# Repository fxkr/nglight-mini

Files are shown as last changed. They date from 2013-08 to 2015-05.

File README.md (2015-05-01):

# nglight-mini r0

## What is it?

A tiny, I2C-controlled 6-channel low-side PWM LED driver based on the PCA9685.
It's just a smaller version of this: http://ng.uavp.ch/moin/Documentation/NGlight

Both schematic and layout are proven.

## Part list?

See parts.csv

## Images

r1-top
r1-bot
r1-both

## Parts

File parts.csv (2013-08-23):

Part | Quantity | Value | Type | Link
C1 | 1 | 100nF | SMD 0805 Cap
C2 | 1 | 10uF |  | https://secure.reichelt.de/?ARTICLE=31906
I2C | 1 | Molex 53261-04 | Molex Picoblade Conn Header 4Pos 1.25MM | http://www.digikey.de/product-detail/de/0532610471/WM7622CT-ND/699109?cur=USD
Q1, Q2, Q3 | 3 | Rohm QS6K1 | Dual N-Ch MOSFET | http://www.digikey.com/product-detail/en/QS6K1TR/QS6K1CT-ND/721551?cur=USD
RN1, RN2 | 2 | 240R | Resistor Array | http://www.digikey.com/product-detail/en/TC164-JR-07220RL/TC164J-220CT-ND/1005375?cur=USD
RN3, RN4 | 2 | 18K | Resistor Array

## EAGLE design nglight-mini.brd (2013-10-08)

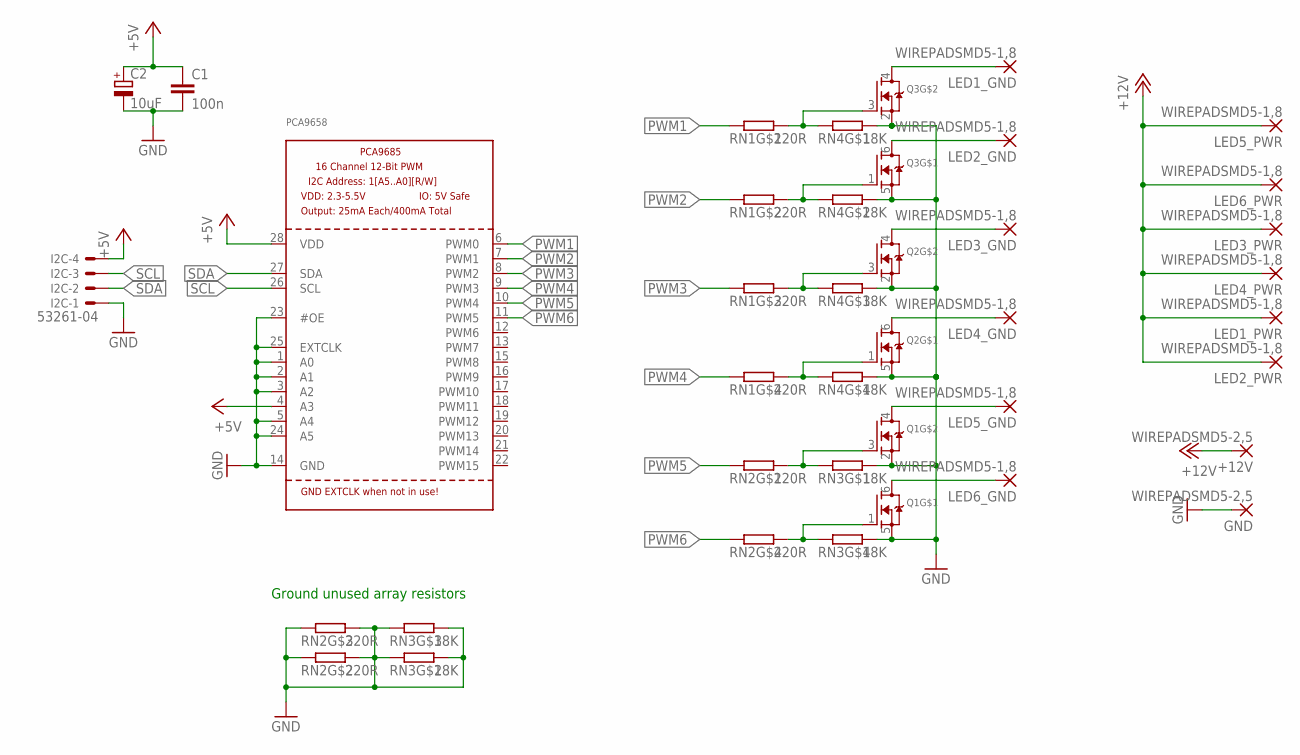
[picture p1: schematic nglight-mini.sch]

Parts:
+12V: WIREPADSMD5-2,5; 5-2,5
C1: 100n; C0805
C2: 10uF; UD-5X5,8_NICHICON
GND: WIREPADSMD5-2,5; 5-2,5
I2C: 53261-04
LED1_GND, LED1_PWR, LED2_GND, LED2_PWR, LED3_GND, LED3_PWR, LED4_GND, LED4_PWR, LED5_GND, LED5_PWR, LED6_GND, LED6_PWR: WIREPADSMD5-1,8; 5-1,8
PCA9658: PCA9685; TSSOP28
Q1, Q2, Q3: MOSFET-N; SOT23-6
RN1, RN2: 220R; 0603_ARRAY_4
RN3, RN4: 18K; 0603_ARRAY_4

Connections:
+5V: C1.1, C2.+, I2C.4, PCA9658.4 (A3), PCA9658.28 (VDD)
+12V: +12V.1, LED1_PWR.1, LED2_PWR.1, LED3_PWR.1, LED4_PWR.1, LED5_PWR.1, LED6_PWR.1
GND: C1.2, C2.-, GND.1, I2C.1, PCA9658.1 (A0), PCA9658.2 (A1), PCA9658.3 (A2), PCA9658.5 (A4), PCA9658.14 (GND), PCA9658.23 (#OE), PCA9658.24 (A5), PCA9658.25 (EXTCLK), Q1.2 (S), Q1.5 (S), Q2.2 (S), Q2.5 (S), Q3.2 (S), Q3.5 (S), RN2.2, RN2.3, RN2.6, RN2.7, RN3.2, RN3.3, RN3.5, RN3.6, RN3.7, RN3.8, RN4.5, RN4.6, RN4.7, RN4.8
LED1: LED1_GND.1, Q3.4 (D)
LED2: LED2_GND.1, Q3.6 (D)
LED3: LED3_GND.1, Q2.4 (D)
LED4: LED4_GND.1, Q2.6 (D)
LED5: LED5_GND.1, Q1.4 (D)
unnamed: LED6_GND.1, Q1.6 (D)
unnamed: Q1.3 (G), RN2.8, RN3.1
unnamed: Q1.1 (G), RN2.5, RN3.4
unnamed: Q2.3 (G), RN1.6, RN4.3
unnamed: Q2.1 (G), RN1.5, RN4.4
unnamed: Q3.3 (G), RN1.8, RN4.1
unnamed: Q3.1 (G), RN1.7, RN4.2
PWM1: PCA9658.6 (PWM0), RN1.1
PWM2: PCA9658.7 (PWM1), RN1.2
PWM3: PCA9658.8 (PWM2), RN1.3
PWM4: PCA9658.9 (PWM3), RN1.4
PWM5: PCA9658.10 (PWM4), RN2.1
PWM6: PCA9658.11 (PWM5), RN2.4
SCL: I2C.3, PCA9658.26 (SCL)
SDA: I2C.2, PCA9658.27 (SDA)

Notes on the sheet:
Ground unused array resistors

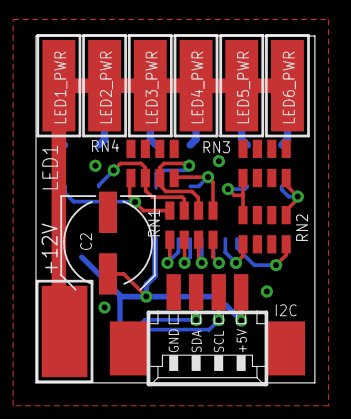
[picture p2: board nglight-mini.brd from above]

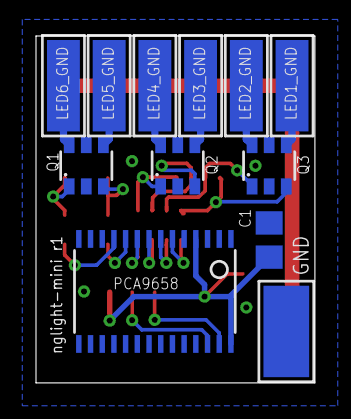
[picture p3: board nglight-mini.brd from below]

Board: 2 copper layers, 15.5 x 19.3 mm, 25 parts (12 on the bottom side), 23 nets.

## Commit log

2013-08-22 Add dual mosfet library
    Part/symbol copied from adafruit library
2013-08-22 Add nglight-mini sch/brd
    [nglight-mini.brd, nglight-mini.sch]
2013-08-23 Minor changes
    [nglight-mini.brd, nglight-mini.sch]
2013-08-23 Add README and (yet incomplete) parts.csv
    [parts.csv]
2013-09-22 Ground unused array resistors
    [nglight-mini.brd, nglight-mini.sch]
2013-10-04 Rev 1; various small improvements, incl.:
    - bigger traces (6 mil -> 10 mil)
    - larger footprint for the big cap
    - remove a small piece of trace between two pins
    that wasn't supposed to be there
    [nglight-mini.brd, nglight-mini.sch]
2013-10-07 Major changes in layout
    The resistor arrays proved hard to solder, so I increased
    the pad size. Due to the tight space constraints, this led
    to relatively big changes in the board. One consequence is
    that traces are now 8mil - a compromise between the 6mil
    that seemed too fine and the 10mil that just wont fit.
    [nglight-mini.brd, nglight-mini.sch]
2013-10-08 Minor trace/via adjustments
    [nglight-mini.brd, nglight-mini.sch]
2013-10-08 Use vector font for all texts
    The fab will use vector fonts either way and due to the size
    difference between the proportional and the vector font they'd
    come out all wrong. Oops.
    [nglight-mini.brd]
2013-10-08 Minor fix (via was very close too pad)
    [nglight-mini.brd]
